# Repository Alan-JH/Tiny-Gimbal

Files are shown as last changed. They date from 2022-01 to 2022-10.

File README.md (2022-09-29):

# Tiny-Gimbal
Code and pcb for two axis self stabilizing servo gimbal using BNO055 and ATTiny16x4 for TJUAV

### V1 
Version for the See3Cam CU135, with 3 axis stabilization. Code was developed and used, but PCB was never manufactured

### V2.1
Due to poor results with the See3Cam, TJUAV has decided to switch to the Sony alpha cameras, specifically the A5100. However, all testing so far has been done with an A5000 camera we already have, which should be dimensionally identical to the A5100, although slower.

Yaw stabilization was removed, for the sake of weight saving and ease of cable management
The mechanism for the gimbal was completely overhauled, needing to be stronger for the camera being 400g instead of 20g
The gimbal was designed for the camera to be easily removeable this time around
A kill switch, and two control buttons (one for centering all servos, and one for putting the gimbal in a position where the camera is easily removeable) were added

Tested and working

### V2.2
Small feature improvements, including:
Zip tie points on the camera mount
Consolidating UART debug connectivity into the UPDI header using a SPDT DIP switch
LED indicators to tell whether the gimbal is centered, in remove position, and powered
U mount X frame instead of an L bracket, to support the camera from both sides and minimize lateral load on the X servo
Single bearing instead of dual bearing Y frame mechanism, to save mass
Sideways X servo, to save mass and size
Integrated buck converter mount on the spar clamp

Tested and working

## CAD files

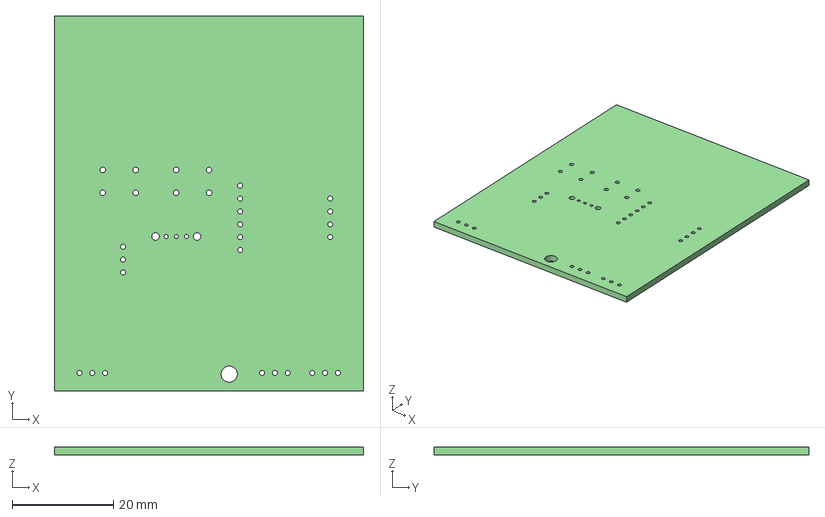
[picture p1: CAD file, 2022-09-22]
ECAD/gimbal/gimbal.step
61.0 x 74.0 x 1.60 mm

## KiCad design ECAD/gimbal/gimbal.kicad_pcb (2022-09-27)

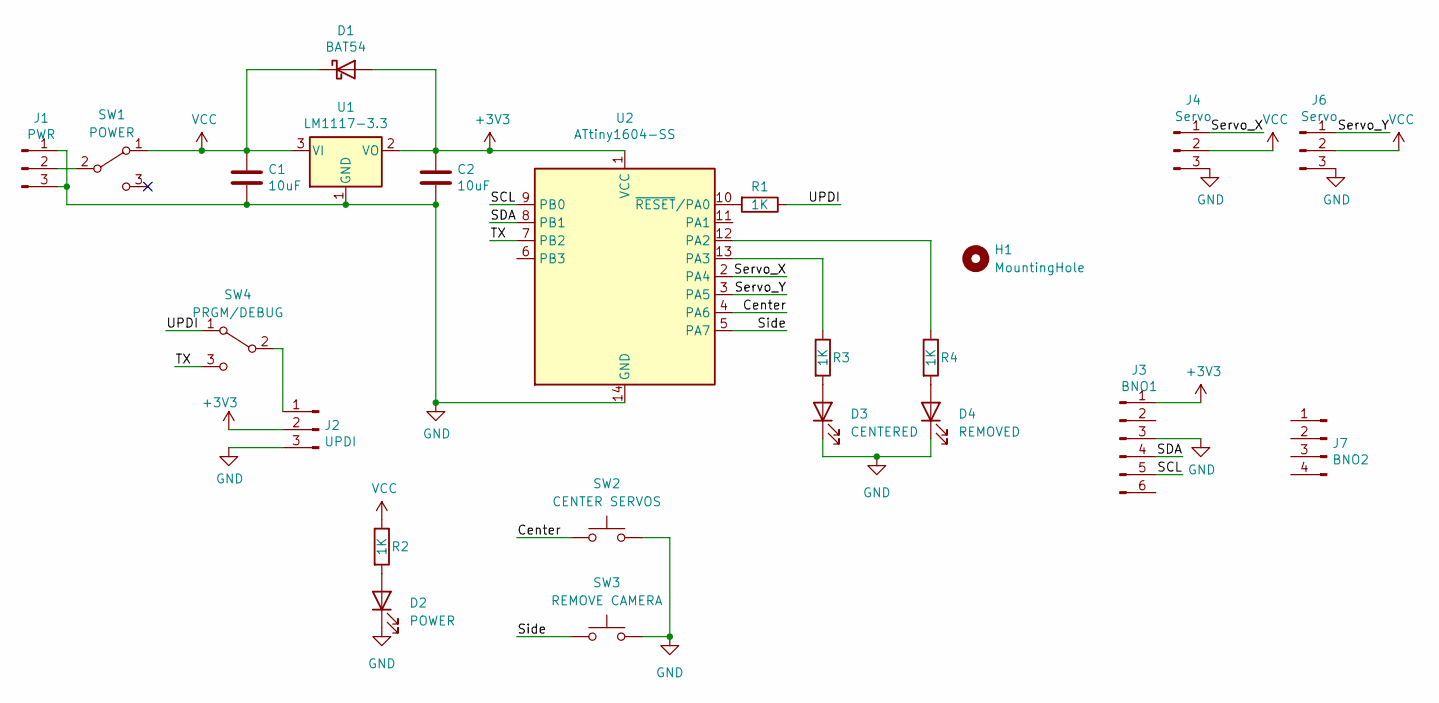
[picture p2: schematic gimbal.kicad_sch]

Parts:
C1, C2: 10uF; C_0805_2012Metric
D1: BAT54; D_SOD-123
D2: POWER; D_0805_2012Metric
D3: CENTERED; D_0805_2012Metric
D4: REMOVED; D_0805_2012Metric
H1: MountingHole; MountingHole_3.2mm_M3
J1: PWR; PinHeader_1x03_P2.54mm_Vertical
J2: UPDI; PinHeader_1x03_P2.54mm_Vertical
J3: BNO1; PinHeader_1x06_P2.54mm_Vertical
J4, J6: Servo; PinHeader_1x03_P2.54mm_Vertical
J7: BNO2; PinHeader_1x04_P2.54mm_Vertical
R1, R2, R3, R4: 1K; R_1206_3216Metric
SW1: POWER; Switch
SW2: CENTER SERVOS; SW_PUSH_6mm
SW3: REMOVE CAMERA; SW_PUSH_6mm
SW4: PRGM/DEBUG; SW_Slide_1P2T_CK_OS102011MS2Q
U1: LM1117-3.3; SOT-223-3_TabPin2
U2: ATtiny1604-SS; SOIC-14_3.9x8.7mm_P1.27mm

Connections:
+3V3: C2.1, D1.2 (A), J2.2, J3.1, U1.2 (VO), U2.1 (VCC)
/Center: SW2.1, U2.4 (PA6)
/SCL: J3.5, U2.9 (PB0)
/SDA: J3.4, U2.8 (PB1)
/Servo_X: J4.1, U2.2 (PA4)
/Servo_Y: J6.1, U2.3 (PA5)
/Side: SW3.1, U2.5 (PA7)
/TX: SW4.3 (C), U2.7 (PB2)
/UPDI: R1.1, SW4.1 (A)
GND: C1.2, C2.2, D2.1 (K), D3.1 (K), D4.1 (K), J1.1, J1.3, J2.3, J3.3, J4.3, J6.3, SW2.2, SW3.2, U1.1 (GND), U2.14 (GND)
unnamed: D2.2 (A), R2.2
unnamed: D3.2 (A), R3.2
unnamed: D4.2 (A), R4.2
unnamed: J1.2, SW1.2 (B)
unnamed: J2.1, SW4.2 (B)
unnamed: R1.2, U2.10 (~RESET/PA0)
unnamed: R3.1, U2.13 (PA3)
unnamed: R4.1, U2.12 (PA2)
VCC: C1.1, D1.1 (K), J4.2, J6.2, R2.1, SW1.1 (A), U1.3 (VI)

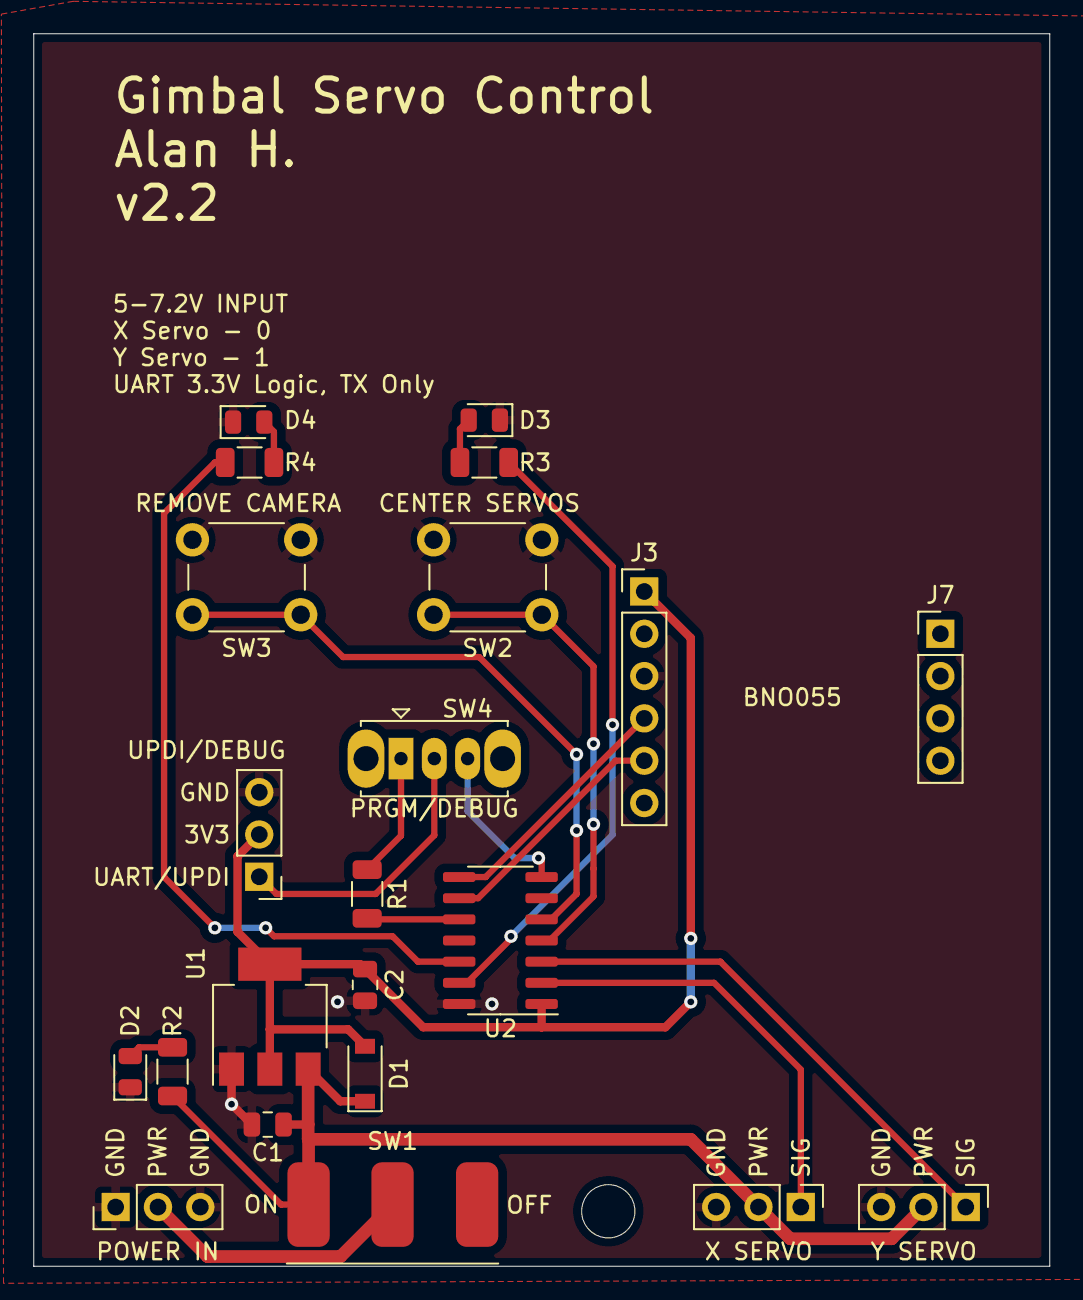
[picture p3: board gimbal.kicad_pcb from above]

Board: 2 copper layers, 61.0 x 74.0 mm, 23 parts (0 on the bottom side), 19 nets.

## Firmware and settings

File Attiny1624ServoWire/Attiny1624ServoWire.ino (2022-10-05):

/*
 * Tiny-Gimbal control code, for board v2.2
 * Alan Hsu
 * 29 September 2022
*/

#include "BNO055Constants.h"
#include <Servo.h> // Use MegaTinyCore implementation of Servo
#include <Wire.h>

Servo servoX;
Servo servoY;

// Servo PWM pin definitions
#define XPIN 0
#define YPIN 1

// Tunable values for center and remove position servo values. 
// Center centers each axis, while remove places the gimbal in a position where the camera is easy to remove
#define XCENTER 1500
#define YCENTER 1450
#define XREMOVE 1900
#define YREMOVE 1450

int x = XCENTER;
int y = YCENTER;

// Minimum and maximum allowable servo pulse width
#define MINPULSE 800
#define MAXPULSE 2200

// Pin definitions for center and remove buttons
#define CENTERPIN 2
#define REMOVEPIN 3

// Pin definitions for center and remove indicator LEDs
#define CENTERLED 10
#define REMOVELED 9

// Center and Remove Button Variables
bool center;
bool centerprevious = 1;
bool removecamera;
bool removeprevious = 1;

// PID Loop Parameters
float XKp = 2.2;
float XKd = 100000;
float XKi = 0;
float YKp = 2.5;
float YKd = 80000;
float YKi = 0;
long long lastreading; // in microseconds
float lastXError;
float lastYError;
float dEx; // Derivative
float dEy;
float intEx; // Integral
float intEy;

void setup() {
  // Set debug UART pins to default, initialize to 57600 baud
  Serial.pins(5, 4);
  Serial.begin(57600, (SERIAL_8N1));

  // Set button and LED indicator pin modes
  pinMode(CENTERPIN, INPUT_PULLUP);
  pinMode(REMOVEPIN, INPUT_PULLUP);
  pinMode(CENTERLED, OUTPUT);
  pinMode(REMOVELED, OUTPUT);

  // Initialize servos, write center position
  servoX.attach(XPIN);
  servoY.attach(YPIN);
  servoX.writeMicroseconds(x);
  servoY.writeMicroseconds(y);

  // Wait for servos to center, then initialize IMU
  delay(1000);
  if (!IMUBegin(OPERATION_MODE_NDOF)){
    while (1){ // If IMU fails to intialize, error message and do not proceed to loop
      Serial.println("Failed to initialize IMU");
      delay(1000);
    }
  } 

  // Set last reading variable for PID
  lastreading = micros();
}


void loop() {
  // Get Euler sensor values
  float euler[3];
  getEuler(euler);
  euler[1] = -1*euler[1]; // Y inversion
  //euler[2] = -1*euler[2]; // X inversion

  // If center button is pressed, toggle center bool and make sure remove is false so both arent true at once
  if (!digitalRead(CENTERPIN) && centerprevious){
    center = !center;
    removecamera = false;
  }

  // If remove button is pressed, toggle remove bool and make sure center is false so both arent true at once
  if (!digitalRead(REMOVEPIN) && removeprevious){
    removecamera = !removecamera;
    center = false;
  }
  centerprevious = digitalRead(CENTERPIN);
  removeprevious = digitalRead(REMOVEPIN);

  // Set LED indicators appropriately
  digitalWrite(REMOVELED, removecamera);
  digitalWrite(CENTERLED, center);

  if (center){ // If center is true, set x and y vals to centered PWM position
    x = XCENTER;
    y = YCENTER;
    intEx = 0; // Make sure integral doesn't go haywire while centered or removed
    intEy = 0;
    lastreading = micros();
  } else if (removecamera){ // If remove is true, set x and y vals to remove PWM position
    x = XREMOVE;
    y = YREMOVE;
    intEx = 0;
    intEy = 0;
    lastreading = micros();
  } else { // If neither center or remove, calculate PID
    float dt = micros() - lastreading;
    dEx = (euler[2] - lastXError);
    intEx += euler[2] * dt;
    x -= XKp*euler[2] + XKd * dEx/dt + XKi * intEx;

    dEy = (euler[1] - lastYError);
    intEy += euler[1] * dt;
    y -= YKp*euler[1] + YKd * dEy/dt + YKi * intEy;
    
    lastreading = micros();
    lastXError = euler[2];
    lastYError = euler[1];

    // Clamp servo PWM values to min and max
    x = min(max(x, MINPULSE), MAXPULSE);
    y = min(max(y, MINPULSE), MAXPULSE);
  }

  // Write to servos
  servoX.writeMicroseconds(x);
  servoY.writeMicroseconds(y);
  
  //Debug print
  Serial.print("SENSOR X: " + String(euler[2]));
  Serial.print(" Y: " + String(euler[1]));
  Serial.println();
  delay(5);
}

// BNO055 Driver implementation:

bool IMUBegin(byte mode){
    Wire.begin();

    uint8_t id = read8(BNO055_CHIP_ID_ADDR);
    if (id != BNO055_ID){
        delay(1000);
        id = read8(BNO055_CHIP_ID_ADDR);
        if (id != BNO055_ID) {
            return false;
        }
    }

    setMode(OPERATION_MODE_CONFIG);

    /* Reset */
    write8(BNO055_SYS_TRIGGER_ADDR, 0x20);
    delay(30);
    while (read8(BNO055_CHIP_ID_ADDR) != BNO055_ID) {
        delay(10);
    }
    delay(50);

    /* Set to normal power mode */
    write8(BNO055_PWR_MODE_ADDR, POWER_MODE_NORMAL);
    delay(10);

    write8(BNO055_PAGE_ID_ADDR, 0);

    write8(BNO055_SYS_TRIGGER_ADDR, 0x0);
    delay(10);
    /* Set the requested operating mode (see section 3.3) */
    setMode(mode);
    delay(20);

    return true;
}

void setMode(byte mode){
    write8(BNO055_OPR_MODE_ADDR, mode);
    delay(30);
}

bool getEuler(float *buf){
    uint8_t wireBuf[6];
    memset(wireBuf, 0, 6);

    readLen(BNO055_EULER_H_LSB_ADDR, wireBuf, 6);

    buf[0] = (float)(((int16_t)wireBuf[0]) | (((int16_t)wireBuf[1]) << 8)) / 16.0;
    buf[1] = (float)(((int16_t)wireBuf[2]) | (((int16_t)wireBuf[3]) << 8)) / 16.0;
    buf[2] = (float)(((int16_t)wireBuf[4]) | (((int16_t)wireBuf[5]) << 8)) / 16.0;

    return true;
}

bool getQuat(float *buf){
    uint8_t wireBuf[8];
    memset(wireBuf, 0, 8);

    readLen(BNO055_EULER_H_LSB_ADDR, wireBuf, 8);

    const double scale = (1.0 / (1 << 14));
    double _w = (float)(((int16_t)wireBuf[0]) | (((int16_t)wireBuf[1]) << 8)) * scale;
    double _x = (float)(((int16_t)wireBuf[2]) | (((int16_t)wireBuf[3]) << 8)) * scale;
    double _y = (float)(((int16_t)wireBuf[4]) | (((int16_t)wireBuf[5]) << 8)) * scale;
    double _z = (float)(((int16_t)wireBuf[6]) | (((int16_t)wireBuf[7]) << 8)) * scale;

    //convert to euler
    double sqw = _w * _w;
    double sqx = _x * _x;
    double sqy = _y * _y;
    double sqz = _z * _z;

    buf[0] = atan2(2.0 * (_x * _y + _z * _w), (sqx - sqy - sqz + sqw))*180/PI;
    buf[1] = asin(-2.0 * (_x * _z - _y * _w) / (sqx + sqy + sqz + sqw))*180/PI;
    buf[2] = atan2(2.0 * (_y * _z + _x * _w), (-sqx - sqy + sqz + sqw))*180/PI;

    return true;
}

bool setRemap(byte remap, byte sign){
    write8(BNO055_AXIS_MAP_CONFIG_ADDR, remap);
    write8(BNO055_AXIS_MAP_SIGN_ADDR, sign);
    return true;
}

byte write8(byte reg, byte data){
    Wire.beginTransmission(BNO055_ADDRESS_A);
    Wire.write(reg);
    Wire.write(data);
    return Wire.endTransmission();
}

byte read8(byte reg){
    Wire.beginTransmission(BNO055_ADDRESS_A);
    Wire.write(reg);
    Wire.endTransmission();
    delay(5);
    Wire.requestFrom(BNO055_ADDRESS_A, 1);
    delay(5);
    if (Wire.available()){
        return Wire.read();
    }
    return 0;
}

bool readLen(byte reg, byte *buf, uint8_t len){
    Wire.beginTransmission(BNO055_ADDRESS_A);
    Wire.write(reg);
    Wire.endTransmission();
    delay(5);
    Wire.requestFrom(BNO055_ADDRESS_A, len);
    delay(5);
    for (int i = 0; i < len; i++){
        buf[i] = Wire.read();
    }
    return true;
}

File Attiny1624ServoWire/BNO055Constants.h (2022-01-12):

/** BNO055 Address A **/
#define BNO055_ADDRESS_A 0x28
/** BNO055 Address B **/
#define BNO055_ADDRESS_B 0x29
/** BNO055 ID **/
#define BNO055_ID 0xA0

/** Offsets registers **/
#define NUM_BNO055_OFFSET_REGISTERS (22)

/* Page id register definition */
#define BNO055_PAGE_ID_ADDR  0X07 

/* PAGE0 REGISTER DEFINITION START*/
#define BNO055_CHIP_ID_ADDR  0x00 
#define BNO055_ACCEL_REV_ID_ADDR  0x01 
#define BNO055_MAG_REV_ID_ADDR  0x02 
#define BNO055_GYRO_REV_ID_ADDR  0x03 
#define BNO055_SW_REV_ID_LSB_ADDR  0x04 
#define BNO055_SW_REV_ID_MSB_ADDR  0x05 
#define BNO055_BL_REV_ID_ADDR  0X06 

/* Accel data register */
#define NO055_ACCEL_DATA_X_LSB_ADDR  0X08 
#define BNO055_ACCEL_DATA_X_MSB_ADDR  0X09 
#define BNO055_ACCEL_DATA_Y_LSB_ADDR  0X0A 
#define BNO055_ACCEL_DATA_Y_MSB_ADDR  0X0B 
#define BNO055_ACCEL_DATA_Z_LSB_ADDR  0X0C 
#define BNO055_ACCEL_DATA_Z_MSB_ADDR  0X0D 

/* Mag data register */
#define BNO055_MAG_DATA_X_LSB_ADDR  0X0E 
#define BNO055_MAG_DATA_X_MSB_ADDR  0X0F 
#define BNO055_MAG_DATA_Y_LSB_ADDR  0X10 
#define BNO055_MAG_DATA_Y_MSB_ADDR  0X11 
#define BNO055_MAG_DATA_Z_LSB_ADDR  0X12 
#define BNO055_MAG_DATA_Z_MSB_ADDR  0X13 

/* Gyro data registers */
#define BNO055_GYRO_DATA_X_LSB_ADDR  0X14 
#define BNO055_GYRO_DATA_X_MSB_ADDR  0X15 
#define BNO055_GYRO_DATA_Y_LSB_ADDR  0X16 
#define BNO055_GYRO_DATA_Y_MSB_ADDR  0X17 
#define BNO055_GYRO_DATA_Z_LSB_ADDR  0X18 
#define BNO055_GYRO_DATA_Z_MSB_ADDR  0X19 

/* Euler data registers */
#define BNO055_EULER_H_LSB_ADDR  0X1A 
#define BNO055_EULER_H_MSB_ADDR  0X1B 
#define BNO055_EULER_R_LSB_ADDR  0X1C 
#define BNO055_EULER_R_MSB_ADDR  0X1D 
#define BNO055_EULER_P_LSB_ADDR  0X1E 
#define BNO055_EULER_P_MSB_ADDR  0X1F 

/* Quaternion data registers */
#define BNO055_QUATERNION_DATA_W_LSB_ADDR  0X20 
#define BNO055_QUATERNION_DATA_W_MSB_ADDR  0X21 
#define BNO055_QUATERNION_DATA_X_LSB_ADDR  0X22 
#define BNO055_QUATERNION_DATA_X_MSB_ADDR  0X23 
#define BNO055_QUATERNION_DATA_Y_LSB_ADDR  0X24 
#define BNO055_QUATERNION_DATA_Y_MSB_ADDR  0X25 
#define BNO055_QUATERNION_DATA_Z_LSB_ADDR  0X26 
#define BNO055_QUATERNION_DATA_Z_MSB_ADDR  0X27 

/* Linear acceleration data registers */
#define BNO055_LINEAR_ACCEL_DATA_X_LSB_ADDR  0X28 
#define BNO055_LINEAR_ACCEL_DATA_X_MSB_ADDR  0X29 
#define BNO055_LINEAR_ACCEL_DATA_Y_LSB_ADDR  0X2A 
#define BNO055_LINEAR_ACCEL_DATA_Y_MSB_ADDR  0X2B 
#define BNO055_LINEAR_ACCEL_DATA_Z_LSB_ADDR  0X2C 
#define BNO055_LINEAR_ACCEL_DATA_Z_MSB_ADDR  0X2D 

/* Gravity data registers */
#define BNO055_GRAVITY_DATA_X_LSB_ADDR  0X2E 
#define BNO055_GRAVITY_DATA_X_MSB_ADDR  0X2F 
#define BNO055_GRAVITY_DATA_Y_LSB_ADDR  0X30 
#define BNO055_GRAVITY_DATA_Y_MSB_ADDR  0X31 
#define BNO055_GRAVITY_DATA_Z_LSB_ADDR  0X32 
#define BNO055_GRAVITY_DATA_Z_MSB_ADDR  0X33 

/* Temperature data register */
#define BNO055_TEMP_ADDR  0X34 

/* Status registers */
#define BNO055_CALIB_STAT_ADDR  0X35 
#define BNO055_SELFTEST_RESULT_ADDR  0X36 
#define BNO055_INTR_STAT_ADDR  0X37 

#define BNO055_SYS_CLK_STAT_ADDR  0X38 
#define BNO055_SYS_STAT_ADDR  0X39 
#define BNO055_SYS_ERR_ADDR  0X3A 

/* Unit selection register */
#define BNO055_UNIT_SEL_ADDR  0X3B 

/* Mode registers */
#define BNO055_OPR_MODE_ADDR  0X3D 
#define BNO055_PWR_MODE_ADDR  0X3E 

#define BNO055_SYS_TRIGGER_ADDR  0X3F 
#define BNO055_TEMP_SOURCE_ADDR  0X40 

/* Axis remap registers */
#define BNO055_AXIS_MAP_CONFIG_ADDR  0X41 
#define BNO055_AXIS_MAP_SIGN_ADDR  0X42 

/* SIC registers */
#define BNO055_SIC_MATRIX_0_LSB_ADDR  0X43 
#define BNO055_SIC_MATRIX_0_MSB_ADDR  0X44 
#define BNO055_SIC_MATRIX_1_LSB_ADDR  0X45 
#define BNO055_SIC_MATRIX_1_MSB_ADDR  0X46 
#define BNO055_SIC_MATRIX_2_LSB_ADDR  0X47 
#define BNO055_SIC_MATRIX_2_MSB_ADDR  0X48 
#define BNO055_SIC_MATRIX_3_LSB_ADDR  0X49 
#define BNO055_SIC_MATRIX_3_MSB_ADDR  0X4A 
#define BNO055_SIC_MATRIX_4_LSB_ADDR  0X4B 
#define BNO055_SIC_MATRIX_4_MSB_ADDR  0X4C 
#define BNO055_SIC_MATRIX_5_LSB_ADDR  0X4D 
#define BNO055_SIC_MATRIX_5_MSB_ADDR  0X4E 
#define BNO055_SIC_MATRIX_6_LSB_ADDR  0X4F 
#define BNO055_SIC_MATRIX_6_MSB_ADDR  0X50 
#define BNO055_SIC_MATRIX_7_LSB_ADDR  0X51 
#define BNO055_SIC_MATRIX_7_MSB_ADDR  0X52 
#define BNO055_SIC_MATRIX_8_LSB_ADDR  0X53 
#define BNO055_SIC_MATRIX_8_MSB_ADDR  0X54 

/* Accelerometer Offset registers */
#define ACCEL_OFFSET_X_LSB_ADDR  0X55 
#define ACCEL_OFFSET_X_MSB_ADDR  0X56 
#define ACCEL_OFFSET_Y_LSB_ADDR  0X57 
#define ACCEL_OFFSET_Y_MSB_ADDR  0X58 
#define ACCEL_OFFSET_Z_LSB_ADDR  0X59 
#define ACCEL_OFFSET_Z_MSB_ADDR  0X5A 

/* Magnetometer Offset registers */
#define MAG_OFFSET_X_LSB_ADDR  0X5B 
#define MAG_OFFSET_X_MSB_ADDR  0X5C 
#define MAG_OFFSET_Y_LSB_ADDR  0X5D 
#define MAG_OFFSET_Y_MSB_ADDR  0X5E 
#define MAG_OFFSET_Z_LSB_ADDR  0X5F 
#define MAG_OFFSET_Z_MSB_ADDR  0X60
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

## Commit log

2022-01-15 Ari's pid changes
2022-01-26 add pcb
    [gimbal-B_Cu.gbr, gimbal-B_Mask.gbr, gimbal-B_Paste.gbr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]
2022-09-11 v2 for A5100 gimbal
    [gimbal-B_Cu.gbr, gimbal-B_Mask.gbr, gimbal-B_Paste.gbr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]
2022-09-11 Add centering and remove buttons
    [gimbal-B_Cu.gbr, gimbal-B_Mask.gbr, gimbal-B_Paste.gbr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]
2022-09-20 code tuning and sch changes for v2.2
    [gimbal.kicad_sch]
2022-09-21 update footprints
    [gimbal.kicad_pcb, gimbal.kicad_sch]
2022-09-22 v2.2 complete
    [gimbal-B_Cu.gbr, gimbal-B_Mask.gbr, gimbal-B_Paste.gbr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]
2022-09-27 PD correction and debugging
    [gimbal-B_Cu.gbr, gimbal-B_Mask.gbr, gimbal-B_Paste.gbr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]
2022-09-29 add center and remove LED functions for v2.2, comment code
2022-10-10 Make PCB easier to remove
